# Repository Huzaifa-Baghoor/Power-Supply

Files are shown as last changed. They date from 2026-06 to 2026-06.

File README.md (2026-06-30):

# Discreete Dual Output DC Power Supply
This is a Custom Designed dual output DC power supply that provides 12V and 5V outputs.
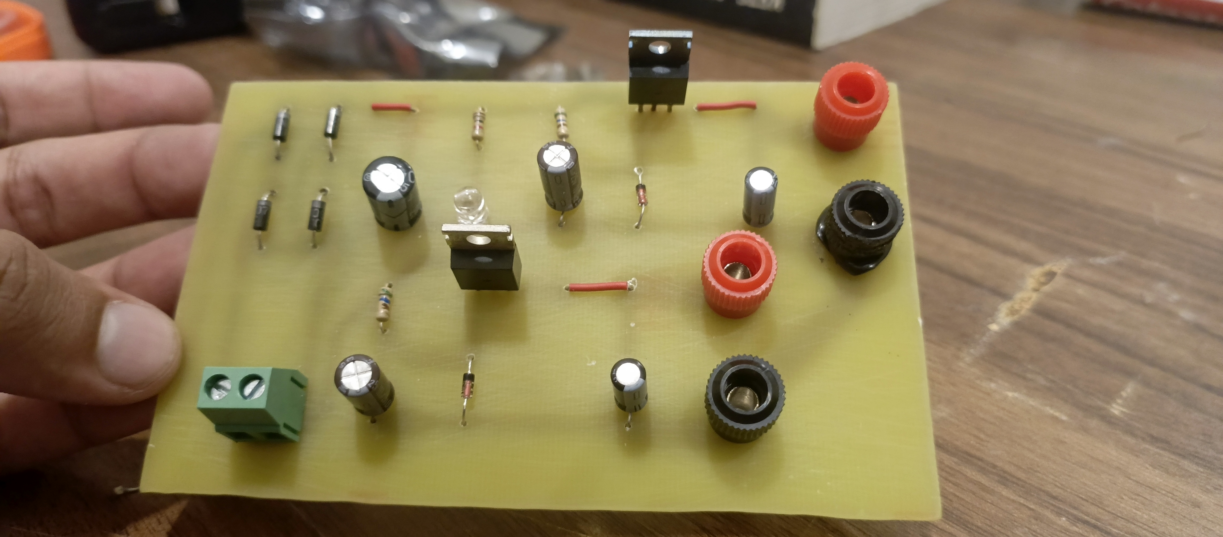
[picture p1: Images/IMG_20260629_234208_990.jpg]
3D


## Working
The circuit takes AC input from Wall Socket and steps it down to 12V then this AC voltage is rectified be 1N4007 Diodes. This 12V DC voltage then goes to a capacitor which decreases the noise and the voltage goes to about 17V. then this voltage is passed through capacitors and zener diodes to provide the 12V and 5V outputs.

## Simulation
This Project is Simulated and Tested in Multisim. It worked fine there and supplied constant voltage under Load.

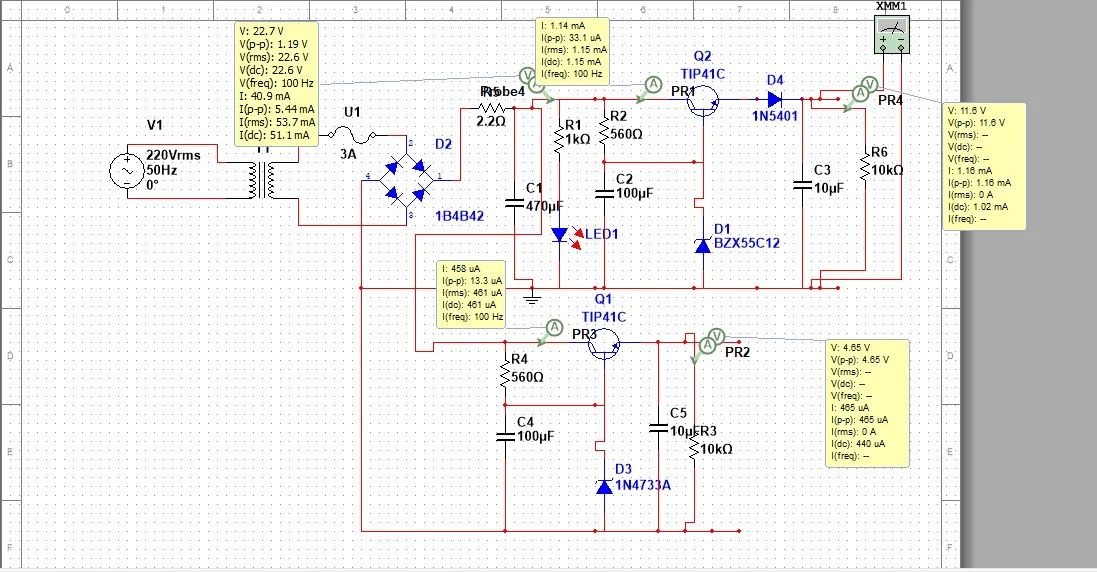
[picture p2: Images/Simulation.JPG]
Simulation


## PCB and Connections
I designed a Custom PCB for this project.

|Schematics|Tracks|
| :---: | :---: |
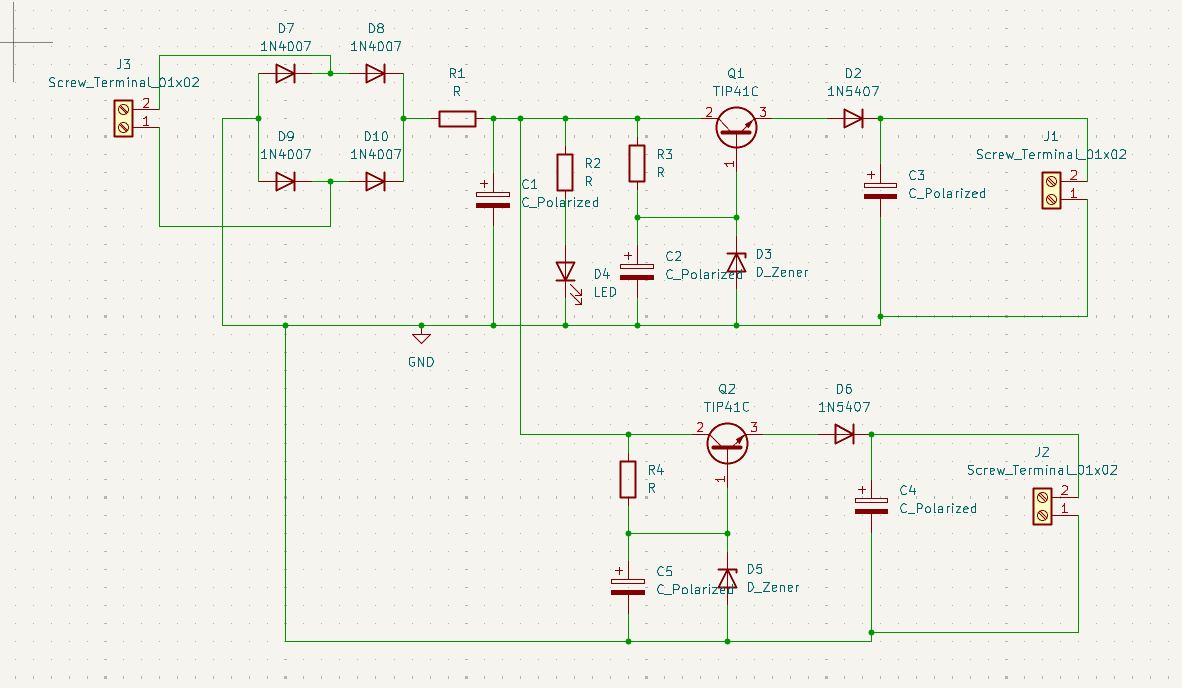
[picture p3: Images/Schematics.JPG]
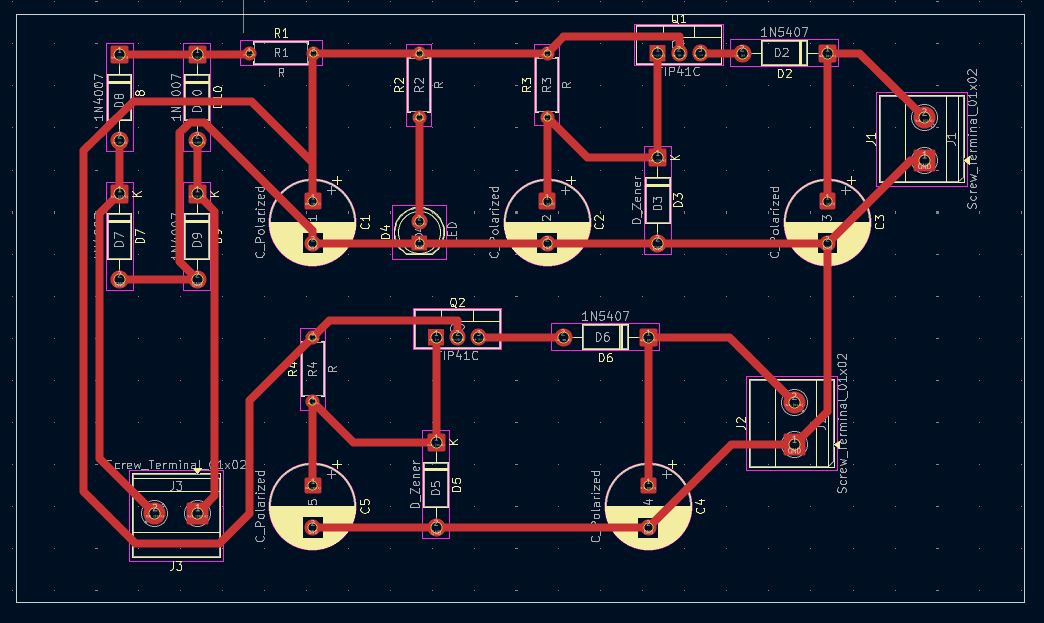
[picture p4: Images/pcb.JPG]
|  |  |

## 3D Case

I also designed a 3D enclosure box for the project that would have 3 holes, 1 for input and 2 for the outputs.
|Schematics|Tracks|
| :---: | :---: |
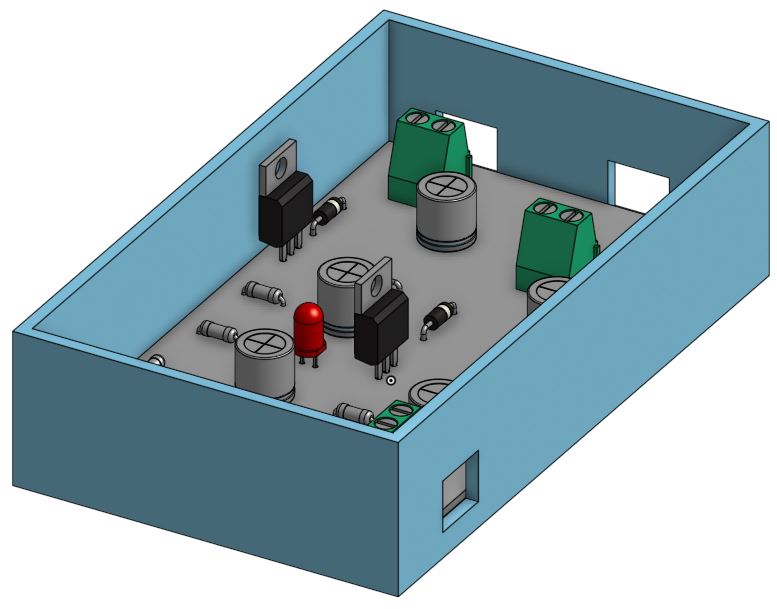
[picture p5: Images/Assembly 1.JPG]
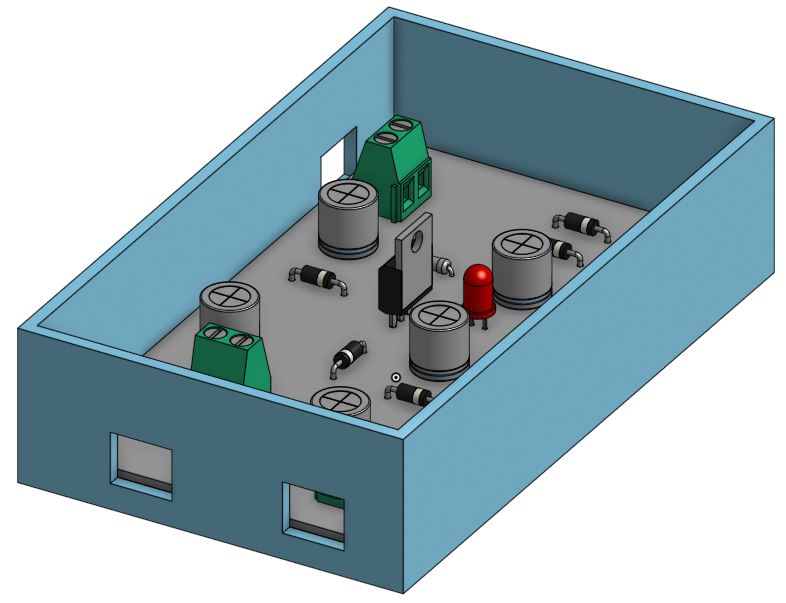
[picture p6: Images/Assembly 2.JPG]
|  |  |

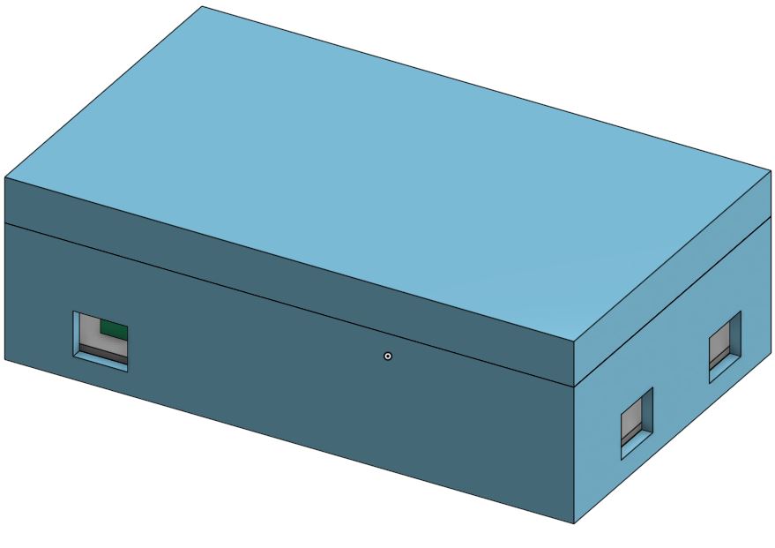
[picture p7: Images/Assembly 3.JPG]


## BOM

| Name | Purpose | Quantity | Total Cost (USD) | Link | Distributor |
| :---: | :---: | :---: | :---: | :---: | :---: |
| Transperency sheets | Printing PCB design | 1 | 8 | [Transperency sheets](https://stationers.pk/products/transparency-sheets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) | Stationers |
| Copper Clad Board | Making PCB | 1 | 7 | [Copper Clad Board](https://epro.pk/product/double-sided-pcb-12x12-in-pakistan/) | Epro |
| Capacitors | Reducing Noise | 1 | 5 | https://a.aliexpress.com/_c4OXuY5T | AliExpress |
| Resistor | Resistance | 4 | 8 | [Resistor](https://www.aliexpress.com/item/1005006898731441.html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) | AliExpress |
| 12v Transformer | Stepping Down 220V to 12V | 1 | 7 | [12v Transformer](https://www.aliexpress.com/item/1005002190993881.html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) | AliExpress |
| 1n5407 | Diode | 1 | 5.9 | [1n5407](https://www.aliexpress.com/item/1005005485365222.html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) | AliExpress |
| Diode | Rectifier | 1 | 3.6 | [Diode](https://www.aliexpress.com/item/1005012369097375.html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) | AliExpress |

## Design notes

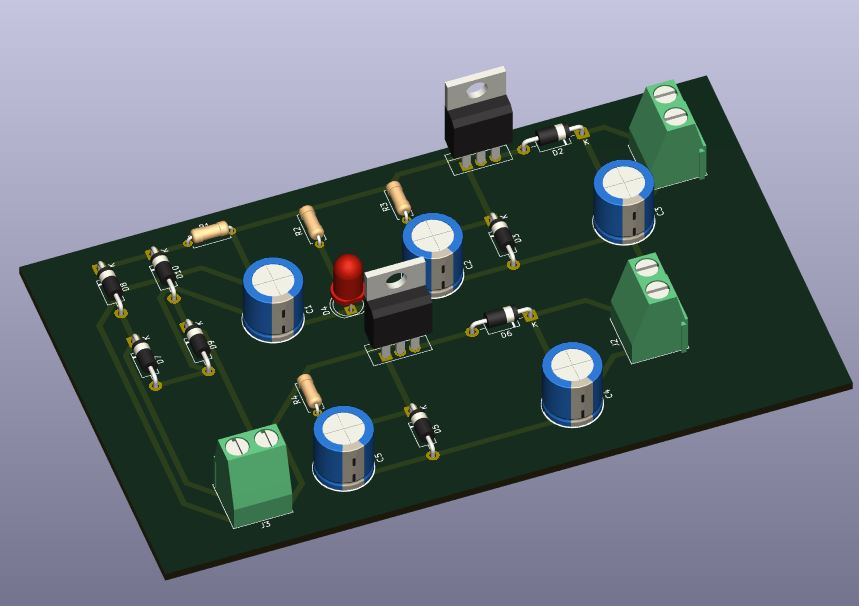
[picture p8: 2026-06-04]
Images/3D.JPG

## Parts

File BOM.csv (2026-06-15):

Name | Purpose | Quantity | Total Cost (USD) | Link | Distributor
Transperency sheets | Printing PCB design | 1 | 8.00 | https://stationers.pk/products/transparency-sheets | Stationers
Copper Clad Board | Making PCB | 1 | 7.00 | https://epro.pk/product/double-sided-pcb-12x12-in-pakistan/ | Epro
Capacitors | Reducing Noise | 3 | 10.00 | https://a.aliexpress.com/_c4OXuY5T | AliExpress
Resistor | Resistance | 4 | 8.00 | https://www.aliexpress.com/item/1005006898731441.html?curPageLogUid=xK5nH0KMlH7Z | AliExpress
12v Transformer | Stepping Down 220V to 12V | 1 | 7.00 | https://www.aliexpress.com/item/1005002190993881.html?curPageLogUid=AV8pa8Zxzb4a | AliExpress
1n5407 | Diode | 1 | 5.90 | https://www.aliexpress.com/item/1005005485365222.html?curPageLogUid=w31Z33jQx7jN | AliExpress
Diode | Rectifier | 1 | 3.60 | https://www.aliexpress.com/item/1005012369097375.html?curPageLogUid=psqZq8pejmBE | AliExpress

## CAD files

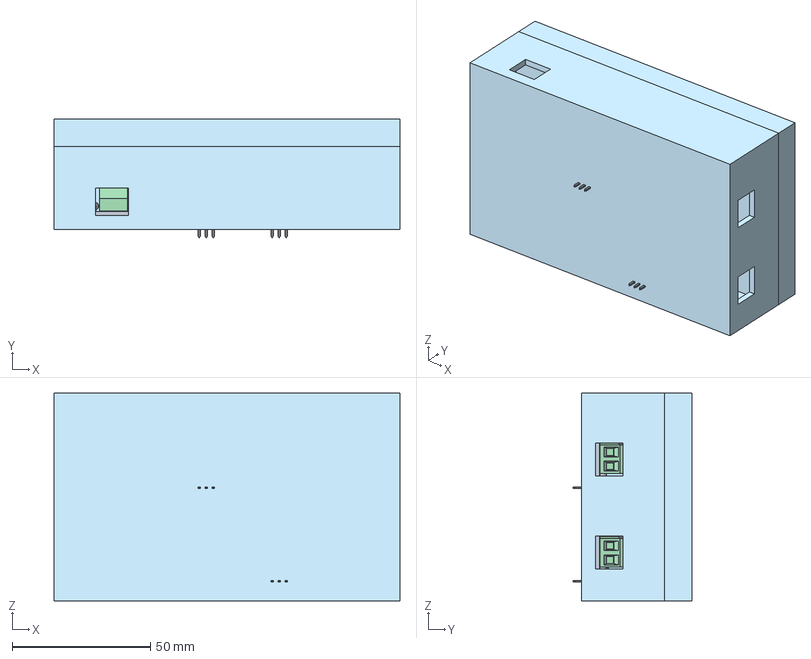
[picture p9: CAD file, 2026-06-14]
3D Files/Assembly 1 (1).step
125.0 x 43.2 x 75.0 mm
R_Axial_DIN0207_L6.3mm_D2.5mm_P7.62mm_Horizontal_1
D_DO-41_SOD81_P10.16mm_Horizontal_3
CP_Radial_D10.0mm_P5.00mm_3
CP_Radial_D10.0mm_P5.00mm_4
D_DO-41_SOD81_P10.16mm_Horizontal_4
R_Axial_DIN0207_L6.3mm_D2.5mm_P7.62mm_Horizontal
D_DO-41_SOD81_P10.16mm_Horizontal_7
TerminalBlock_Phoenix_MKDS-1,5-2-5.08_1x02_P5.08mm_Horizontal
TO-220-3_Vertical_1
TerminalBlock_Phoenix_MKDS-1,5-2-5.08_1x02_P5.08mm_Horizontal_1
CP_Radial_D10.0mm_P5.00mm
Power Suply_PCB
TO-220-3_Vertical
R_Axial_DIN0207_L6.3mm_D2.5mm_P7.62mm_Horizontal_2
TerminalBlock_Phoenix_MKDS-1,5-2-5.08_1x02_P5.08mm_Horizontal_2
D_DO-41_SOD81_P10.16mm_Horizontal_2
CP_Radial_D10.0mm_P5.00mm_2
D_DO-41_SOD81_P10.16mm_Horizontal_5
D_DO-41_SOD81_P10.16mm_Horizontal_1
CP_Radial_D10.0mm_P5.00mm_1
D_DO-41_SOD81_P10.16mm_Horizontal_6
D_DO-41_SOD81_P10.16mm_Horizontal
LED_D5.0mm
R_Axial_DIN0207_L6.3mm_D2.5mm_P7.62mm_Horizontal_3

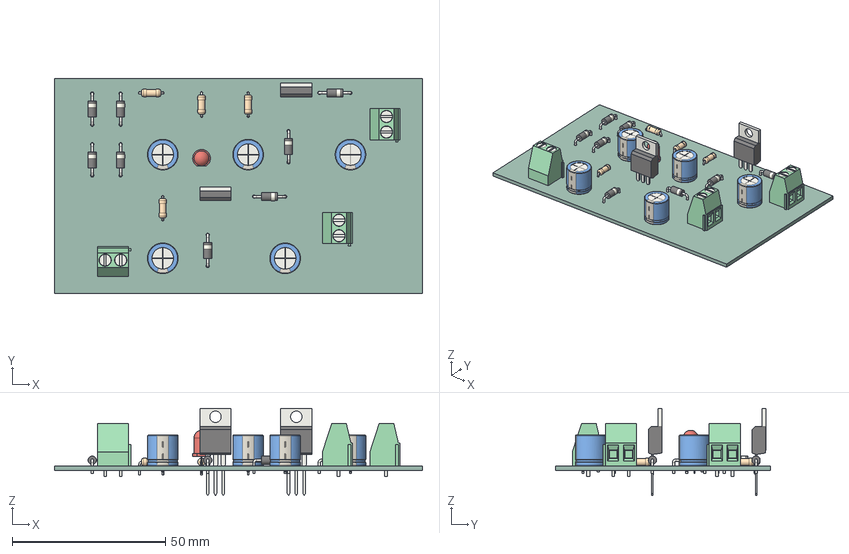
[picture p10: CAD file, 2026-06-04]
PCB/Power Suply.step
120.0 x 70.0 x 28.5 mm
D_DO-41_SOD81_P10.16mm_Horizontal x 8
CP_Radial_D10.0mm_P5.00mm x 5
R_Axial_DIN0207_L6.3mm_D2.5mm_P7.62mm_Horizontal x 4
LED_D5.0mm
TO-220-3_Vertical x 2
TerminalBlock_Phoenix_MKDS-1,5-2-5.08_1x02_P5.08mm_Horizontal x 3
Power Suply_PCB

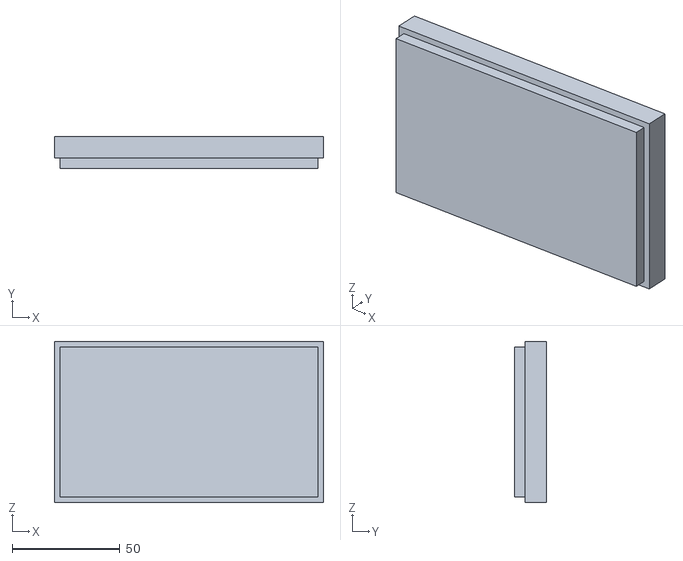
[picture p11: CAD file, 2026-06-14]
3D Files/Lid (1).stl
125.0 x 15.0 x 75.0

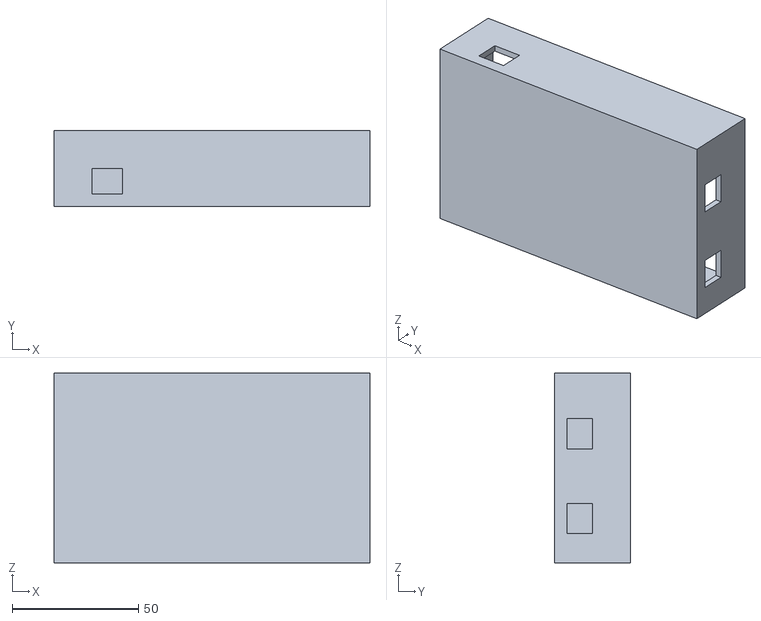
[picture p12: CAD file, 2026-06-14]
3D Files/Box (1).stl
125.0 x 30.0 x 75.0

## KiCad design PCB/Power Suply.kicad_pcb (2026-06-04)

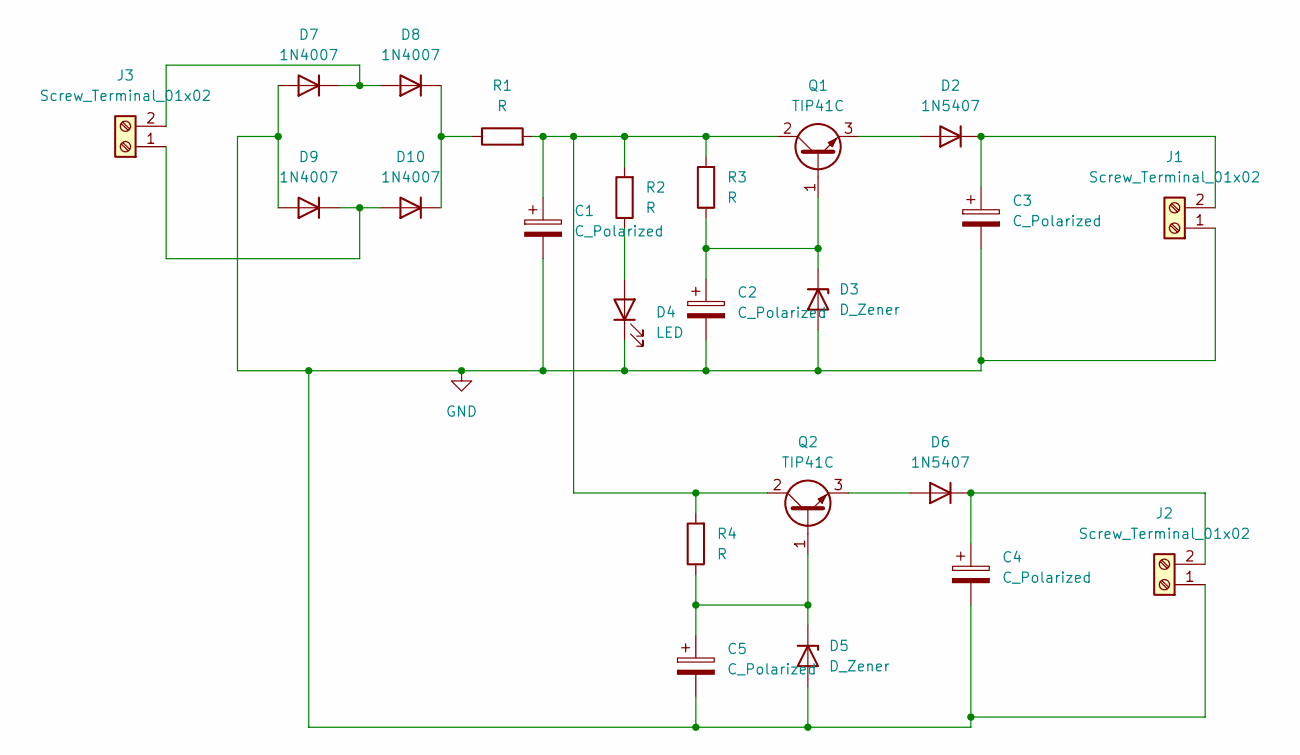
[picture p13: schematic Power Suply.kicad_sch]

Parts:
C1, C2, C3, C4, C5: C_Polarized; CP_Radial_D10.0mm_P5.00mm
D2, D6: 1N5407; D_DO-41_SOD81_P10.16mm_Horizontal
D3, D5: D_Zener; D_DO-41_SOD81_P10.16mm_Horizontal
D4: LED; LED_D5.0mm
D7, D8, D9, D10: 1N4007; D_DO-41_SOD81_P10.16mm_Horizontal
J1, J2, J3: Screw_Terminal_01x02; TerminalBlock_Phoenix_MKDS-1,5-2-5.08_1x02_P5.08mm_Horizont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
Q1, Q2: TIP41C; TO-220-3_Vertical
R1, R2, R3, R4: R; R_Axial_DIN0207_L6.3mm_D2.5mm_P7.62mm_Horizontal

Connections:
GND: C1.2, C2.2, C3.2, C4.2, C5.2, D3.2 (A), D4.1 (K), D5.2 (A), D7.2 (A), D9.2 (A), J1.1, J2.1
unnamed: D2.2 (A), Q1.3 (E)
unnamed: C3.1, D2.1 (K), J1.2
unnamed: C2.1, D3.1 (K), Q1.1 (B), R3.1
unnamed: D4.2 (A), R2.1
unnamed: C5.1, D5.1 (K), Q2.1 (B), R4.1
unnamed: D6.2 (A), Q2.3 (E)
unnamed: C4.1, D6.1 (K), J2.2
unnamed: D7.1 (K), D8.2 (A), J3.2
unnamed: D9.1 (K), D10.2 (A), J3.1
unnamed: D8.1 (K), D10.1 (K), R1.1
unnamed: C1.1, Q1.2 (C), Q2.2 (C), R1.2, R2.2, R3.2, R4.2

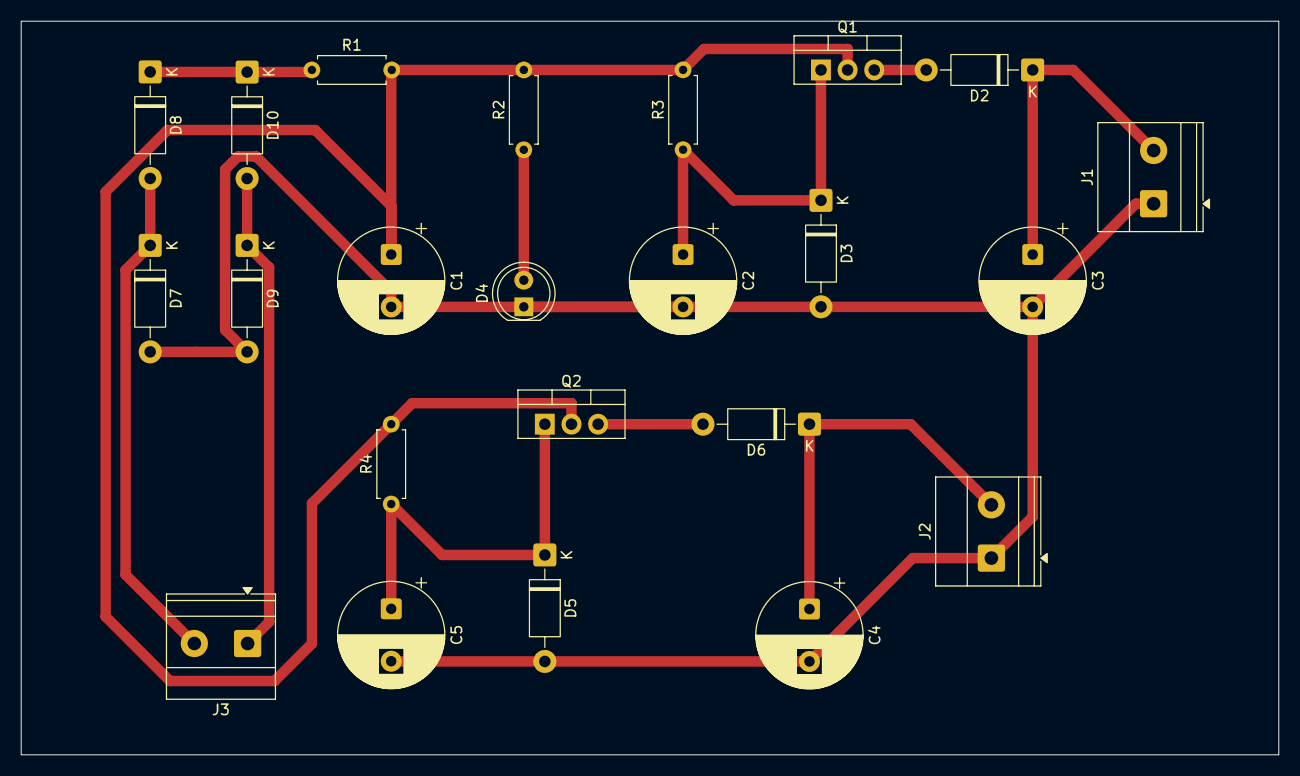
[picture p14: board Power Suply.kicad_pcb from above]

Board: 2 copper layers, 120.0 x 70.0 mm, 23 parts (0 on the bottom side), 12 nets.

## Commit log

2026-05-17 PCB v1
    [Power Suply.kicad_pcb, Power Suply.kicad_sch]
2026-06-14 Added 3D Files
    [Assembly 1 (1).step, Box (1).stl, Lid (1).stl]
2026-06-15 Add link for capacitors in README materials list
    Added link for capacitors in the materials table.
2026-06-15 Update capacitor link in BOM.csv
    [BOM.csv]
2026-06-15 Modify capacitors entry in components list
    Updated the quantity and cost of capacitors in the components list.
